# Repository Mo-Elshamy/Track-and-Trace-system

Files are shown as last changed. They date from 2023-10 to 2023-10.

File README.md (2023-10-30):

# Track-and-Trace-system 
Used on a medicine production line 
This project is a base module that can be customized for specific purposes.

Youtube link : https://youtu.be/wrTnvzPaxEU

In this project, my role was to establish communication with a microcontroller via a Python app, with the microcontroller responding to any action such as rejection or approval in the production line.

mainboard

## Python code:

This code is a demonstration of the app code that is responsible for of processing the image from the camera. When the object is detected by the microcontroller, the first section decodes the QR code, and the second section extracts the text from a frame saved as an image.The text from the QR code is then compared to the text from the captured image to make a decision.
The code communicates with the serial library by specifying the port and the baud rate.

## Microconntroller code:

This code is responsible for the app code's actions and also sends a string to the app that acts as a trigger to notify the app code when an object is detected using an IR sensor.

## Hardware circuit:

This circuit is designed to have:
* 4 output relay
* 2 IR sesonrs
* RGBA 12v output connection
* 12v, 5v and GND output
* Input power 24V

## System schematic:


## Pico pinout connection:


## layout design:


## Crcuit:


## Test:







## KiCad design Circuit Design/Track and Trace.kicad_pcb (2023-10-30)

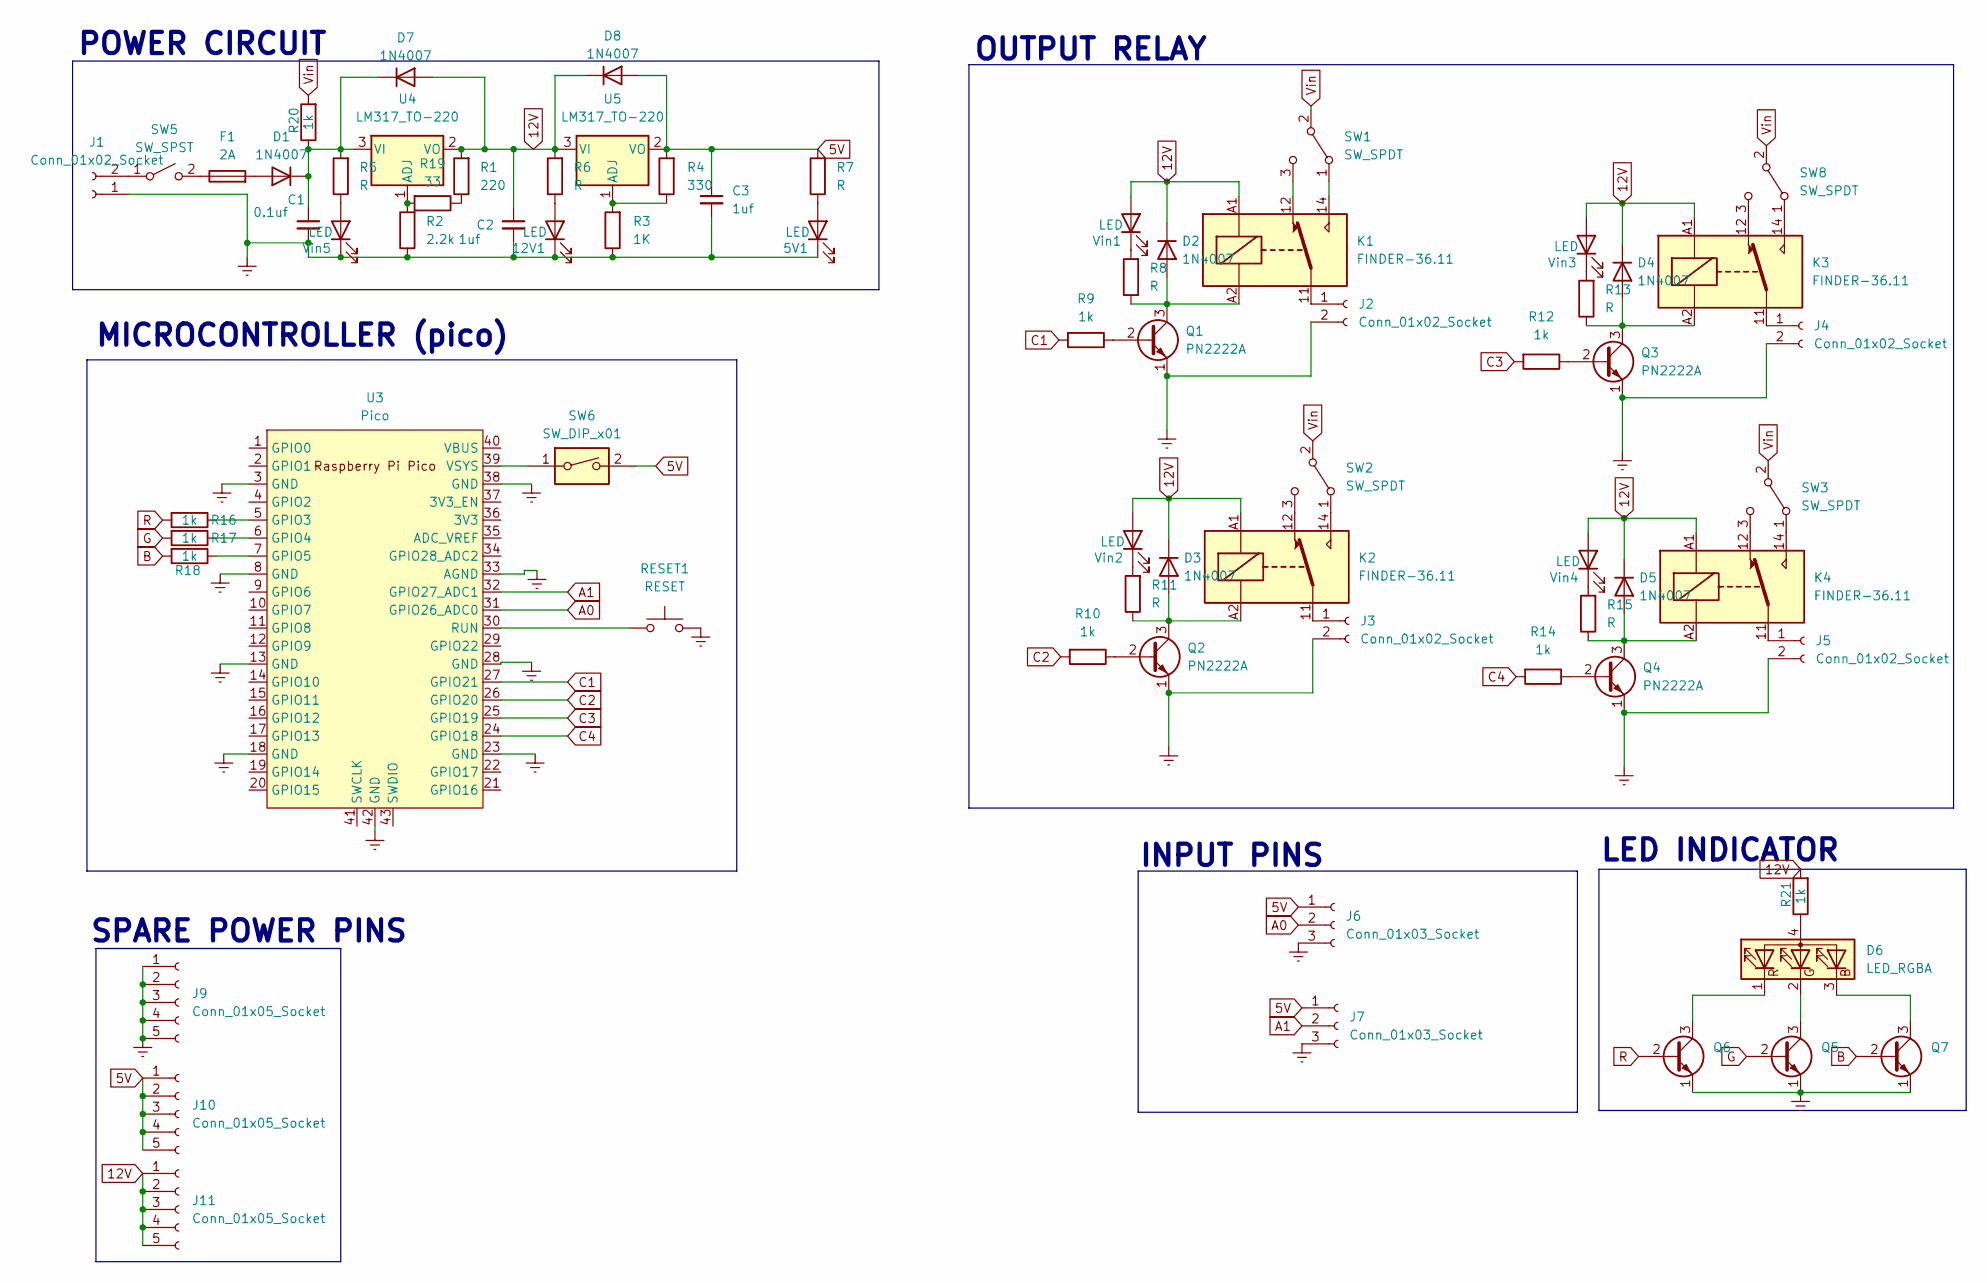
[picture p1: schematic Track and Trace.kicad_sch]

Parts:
5V1, 12V1: LED; LED_D3.0mm
C1: 0.1uf; CP_Radial_D4.0mm_P2.00mm
C2, C3: 1uf; CP_Radial_D4.0mm_P2.00mm
D1, D2, D3, D4, D5, D7, D8: 1N4007; D_DO-41_SOD81_P10.16mm_Horizontal
D6: LED_RGBA; JST_EH_B4B-EH-A_1x04_P2.50mm_Vertical
F1: 2A; Fuseholder_Littelfuse_100_series_5x20mm
J1, J2, J3, J4, J5: Conn_01x02_Socket; TerminalBlock_bornier-2_P5.08mm
J6, J7: Conn_01x03_Socket; JST_EH_B3B-EH-A_1x03_P2.50mm_Vertical
J9, J10, J11: Conn_01x05_Socket; TerminalBlock_bornier-5_P5.08mm
K1, K2, K3, K4: FINDER-36.11; Relay_SPDT_Finder_36.11
Q1, Q2, Q3, Q4, Q5, Q6, Q7: PN2222A; TO-92_Inline
R1: 220; R_Axial_DIN0207_L6.3mm_D2.5mm_P10.16mm_Horizontal
R2: 2.2k; R_Axial_DIN0207_L6.3mm_D2.5mm_P10.16mm_Horizontal
R3: 1K; R_Axial_DIN0207_L6.3mm_D2.5mm_P10.16mm_Horizontal
R4: 330; R_Axial_DIN0207_L6.3mm_D2.5mm_P10.16mm_Horizontal
R5, R6, R7, R8, R11, R13, R15: R; R_Axial_DIN0207_L6.3mm_D2.5mm_P10.16mm_Horizontal
R9, R10, R12, R14, R16, R17, R18, R20, R21: 1k; R_Axial_DIN0207_L6.3mm_D2.5mm_P10.16mm_Horizontal
R19: 33; R_Axial_DIN0207_L6.3mm_D2.5mm_P10.16mm_Horizontal
RESET1: RESET; SW_PUSH_6mm_H5mm
SW1, SW2, SW3, SW8: SW_SPDT; PinHeader_1x03_P2.54mm_Vertical
SW5: SW_SPST; TerminalBlock_bornier-2_P5.08mm
SW6: SW_DIP_x01; SW_DIP_SPSTx01_Piano_10.8x4.1mm_W7.62mm_P2.54mm
U3: Pico; RPi_Pico_SMD_TH
U4, U5: LM317_TO-220; TO-220-3_Vertical
Vin1, Vin2, Vin3, Vin4, Vin5: LED; LED_D3.0mm

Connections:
5V: C3.1, D8.2 (A), J6.1, J7.1, J10.1, J10.2, J10.3, J10.4, J10.5, R4.2, R7.2, SW6.2, U5.2 (VO)
12V: C2.1, D2.1 (K), D3.1 (K), D4.1 (K), D5.1 (K), D7.2 (A), D8.1 (K), J11.1, J11.2, J11.3, J11.4, J11.5, K1.A1, K2.A1, K3.A1, K4.A1, R1.2, R6.2, R21.2, U4.2 (VO), U5.3 (VI), Vin1.2 (A), Vin2.2 (A), Vin3.2 (A), Vin4.2 (A)
A0: J6.2, U3.31 (GPIO26_ADC0)
A1: J7.2, U3.32 (GPIO27_ADC1)
B: Q7.2 (B), R18.2
C1: R9.2, U3.27 (GPIO21)
C2: R10.2, U3.26 (GPIO20)
C3: R12.2, U3.25 (GPIO19)
C4: R14.2, U3.24 (GPIO18)
Earth: 5V1.1 (K), 12V1.1 (K), C1.2, C2.2, C3.2, J1.1, J2.2, J3.2, J4.2, J5.2, J6.3, J7.3, J9.1, J9.2, J9.3, J9.4, J9.5, Q1.1 (E), Q2.1 (E), Q3.1 (E), Q4.1 (E), Q5.1 (E), Q6.1 (E), Q7.1 (E), R2.1, R3.1, RESET1.2, U3.3 (GND), U3.8 (GND), U3.13 (GND), U3.18 (GND), U3.23 (GND), U3.28 (GND), U3.33 (AGND), U3.38 (GND), U3.42 (GND), Vin5.1 (K)
G: Q5.2 (B), R17.2
unnamed: 5V1.2 (A), R7.1
unnamed: 12V1.2 (A), R6.1
unnamed: D1.2 (A), F1.2
unnamed: C1.1, D1.1 (K), D7.1 (K), R5.2, R20.1, U4.3 (VI)
unnamed: D2.2 (A), K1.A2, Q1.3 (C), R8.1
unnamed: D3.2 (A), K2.A2, Q2.3 (C), R11.1
unnamed: D4.2 (A), K3.A2, Q3.3 (C), R13.1
unnamed: D5.2 (A), K4.A2, Q4.3 (C), R15.1
unnamed: D6.4 (A), R21.1
unnamed: D6.3 (BK), Q7.3 (C)
unnamed: D6.2 (GK), Q5.3 (C)
unnamed: D6.1 (RK), Q6.3 (C)
unnamed: J1.2, SW5.1 (A)
unnamed: J2.1, K1.11
unnamed: J3.1, K2.11
unnamed: J4.1, K3.11
unnamed: J5.1, K4.11
unnamed: Q1.2 (B), R9.1
unnamed: Q2.2 (B), R10.1
unnamed: Q3.2 (B), R12.1
unnamed: Q4.2 (B), R14.1
unnamed: R1.1, R19.1
unnamed: K1.14, SW1.1 (A)
unnamed: K1.12, SW1.3 (C)
unnamed: K2.14, SW2.1 (A)
unnamed: K2.12, SW2.3 (C)
unnamed: K4.14, SW3.1 (A)
unnamed: K4.12, SW3.3 (C)
unnamed: F1.1, SW5.2 (B)
unnamed: K3.14, SW8.1 (A)
unnamed: K3.12, SW8.3 (C)
unnamed: R16.1, U3.5 (GPIO3)
unnamed: R17.1, U3.6 (GPIO4)
unnamed: R18.1, U3.7 (GPIO5)
unnamed: RESET1.1, U3.30 (RUN)
unnamed: SW6.1, U3.39 (VSYS)
unnamed: R2.2, R19.2, U4.1 (ADJ)
unnamed: R3.2, R4.1, U5.1 (ADJ)
unnamed: R8.2, Vin1.1 (K)
unnamed: R11.2, Vin2.1 (K)
unnamed: R13.2, Vin3.1 (K)
unnamed: R15.2, Vin4.1 (K)
unnamed: R5.1, Vin5.2 (A)
R: Q6.2 (B), R16.2
Vin: R20.2, SW1.2 (B), SW2.2 (B), SW3.2 (B), SW8.2 (B)

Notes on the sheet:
SPARE POWER PINS
LED INDICATOR
MICROCONTROLLER (pico)
OUTPUT RELAY
INPUT PINS
POWER CIRCUIT

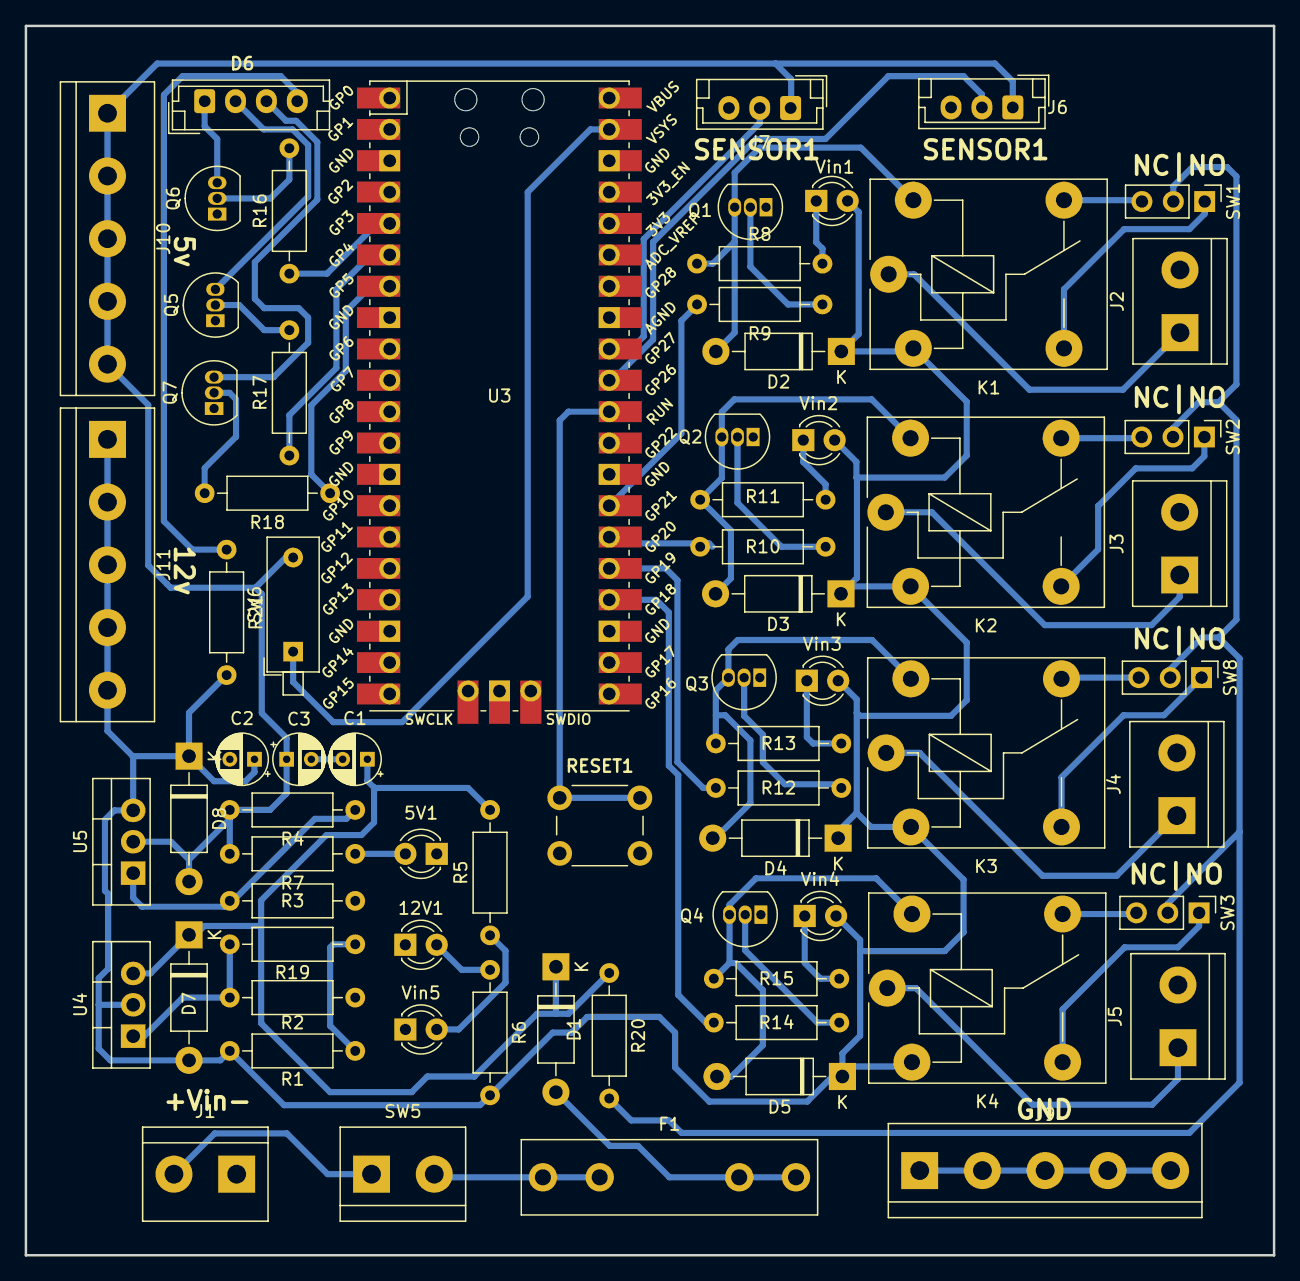
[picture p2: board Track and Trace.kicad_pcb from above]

Board: 2 copper layers, 101.1 x 99.6 mm, 71 parts (0 on the bottom side), 56 nets.

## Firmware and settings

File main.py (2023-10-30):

import serial   #serial library to comunicate to the microcontroller
import cv2
import os
from pyzbar import pyzbar    #Qrcode library
import pytesseract as tess   #text library
tess.pytesseract.tesseract_cmd = r'C:\Program Files\Tesseract-OCR\tesseract.exe'  #the path differ from pc to another
from PIL import Image


camera = cv2.VideoCapture(1)  #camera used for capturing (0 is the built in camera)
ser = serial.Serial('COM6', 9600)  # Replace 'COM1' with the actual port name


while True:

    while ser.in_waiting >= 0:

        msg = ser.readline().decode('utf-8').rstrip()  #read data and store it
        print(msg)


        if msg == "cap":                               #cap is send by the microcontroller when object is detected

            _, frame = camera.read()

            cv2.imwrite('test.jpg', frame)             #savig image (for text reading)

            decodedObjectes = pyzbar.decode(frame)      #Read the Qr code and store it
            decodedStrings = []

            for obj in decodedObjectes:
               QRdata = obj.data.decode('utf-8')                 # Decode the bytes object into a string
               print(" QR Data:", obj.data.decode('utf-8'))      # Print the decoded string
               decodedStrings.append(obj.data.decode('utf-8'))   # Append the decoded string to the list

            QRdata = decodedStrings
            print(QRdata)
            print("*********************************************")


            img = Image.open('test.jpg')                         
            text = tess.image_to_string(img)                     #Extracting the text from the saved img

            print("Text Data:",text)

            if QRdata and text:

                QRdata = QRdata.replace(" ", "").replace("\n", "")  
                text = text.replace(" ", "").replace("\n", "")      
            
                QRdata = QRdata.lower()
                text = text.lower()

                if QRdata == text:
                    print("accepted")
                    ser.write("accepted".strip().encode())
                else:
                    print("rejected")
                    ser.write("rejected".strip().encode())

            else:
                print("error")
                ser.write("rejected".strip().encode())

            os.remove('test.jpg')

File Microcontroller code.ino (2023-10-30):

#define Detect0 26
#define Detect1 27
#define red 3
#define green 4
#define blue 5
#define sw0 21
#define sw1 20
#define sw2 19
#define sw3 18

int num = 0 ;
String x ;


void start ();

void setup ()
{
  Serial.begin(9600);

  pinMode(red, OUTPUT);
  pinMode(green, OUTPUT);
  pinMode(blue, OUTPUT);
  pinMode(sw0, OUTPUT);
  pinMode(sw1, OUTPUT);
  pinMode(sw2, OUTPUT);
  pinMode(sw3, OUTPUT);

  pinMode(Detect0, INPUT);
  pinMode(Detect1, INPUT);
}

void loop(){

  start();

  Serial.print("xx");

  while(Serial.available()>=0){
    // Serial.println("connected");
    if(digitalRead(Detect1) == 0){
      while(digitalRead(Detect1) == 0){
      Serial.println("cap");    
      x =Serial.readStringUntil('\n');
        if (x== "rejected"){
          digitalWrite(sw2, 1);
          delay(100);
          digitalWrite(sw2, 0);
        }
        
        else if (x=="error"){
          digitalWrite(sw1, 1);
          delay(100);
          digitalWrite(sw1, 0);
        }
        else if (x =="accepted"){
          digitalWrite(sw0, 1);
          delay(100);
          digitalWrite(sw0, 0);
        }
        else{
         // Serial.println("Error");
        }
      
       while(digitalRead(Detect1) == 0){}
      }
    }
  }
}


void start (){
  digitalWrite(red, 1);
  digitalWrite(green, 1);
  digitalWrite(blue, 1);
  digitalWrite(sw0, 0);
  digitalWrite(sw1, 0);
  digitalWrite(sw2, 0);
  digitalWrite(sw3, 0);
}
